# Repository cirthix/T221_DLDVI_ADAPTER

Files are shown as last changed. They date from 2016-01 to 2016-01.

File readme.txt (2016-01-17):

This is the T221 DLDVI Adapter.  It allows DLDVI video signals to drive the DG5/DGM/DGP variants of the IBM T221 and is functionally similar to the IBM 'converter box'.
	
The 'Outputs' directory contains all information needed to create or debug one.

There have been minimal (mostly cosmetic) changes from the actual production run due some file conversion and cleanup.

See 'LICENSE.TXT' for license information.

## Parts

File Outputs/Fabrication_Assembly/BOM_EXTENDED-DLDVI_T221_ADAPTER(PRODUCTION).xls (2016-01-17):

Quantity | Designator | Footprint | Library Reference | Tolerance(%) | Value | Voltage Rating | Manufacturer | Part | Notes | Power Dissipation(mW) | Supplier | Supplier Part #
3.0 | C44, C45, C46 | SMD_0402_CAP | Cap Semi | 10% | 100nF | 10V | Generic | Capacitor | Specified voltage is minimum. May substitute for higher-voltage part. May substitute with tighter tolerance part. |  | Digikey | GRM155R62A104ME14D
2.0 | DVI1, DVI2 | DVI-I CONNECTOR | DVI-I CONNECTOR |  |  |  | TE Connectivity | 1-1734148-1 | Verify footprint before substituting |  | Digikey | 1-1734148-1-ND
2.0 | J2, J3 | LFH-60 | LFH-60 CONNECTOR |  |  |  | Molex | 0015922250 |  |  | Digikey | WM5015-ND
3.0 | Q1, Q3, Q4 | SOT323 | NMOS |  |  | 60Vds 20Vgs | Fairchild | BSS138k | If substituting, verify threshold voltage compatibility |  | Digikey | BSS138KCT-ND
1.0 | Q2 | SOT323 | PMOS |  |  | 50Vds 20Vgs | Fairchild | BSS84 | If substituting, verify threshold voltage compatibility |  | Digikey | BSS84CT-ND
12.0 | R6, R7, R8, R9, R10, R11, R12, R13, R14, R15, R16, R17 | SMD_0402_RES | RES1 | 5% | 16.7R |  | Generic | Resistor | May substitute with tighter tolerance part. | 63 | Digikey | P16.5LCT-ND
2.0 | R18, R19 | SMD_0402_RES | RES1 | 5% | 1KR |  | Generic | Resistor | May substitute with tighter tolerance part. | 63 | Digikey | P1.00KLCT-ND
9.0 | R20, R21, R22, R23, R25, R26, R27, R28, R29 | SMD_0402_RES | Res3 | 5% | 10K |  | Generic | Resistor | May substitute with tighter tolerance part. | 63 | Digikey | P10.0KLCT-ND
3.0 | U5, U6, U7 | SOIC8 + MSOP8 inline | 24C02 |  |  | 5V | ST Microelectronics | M24C02-FMN6TP | Other 5V 1K eeproms will work. |  | Digikey | 497-15748-1-ND

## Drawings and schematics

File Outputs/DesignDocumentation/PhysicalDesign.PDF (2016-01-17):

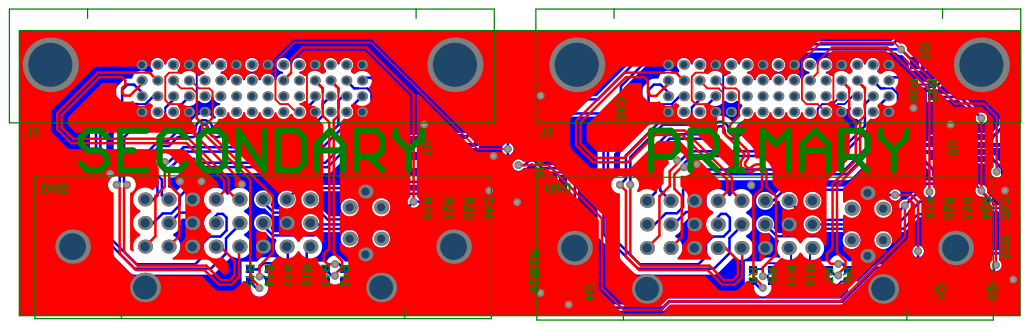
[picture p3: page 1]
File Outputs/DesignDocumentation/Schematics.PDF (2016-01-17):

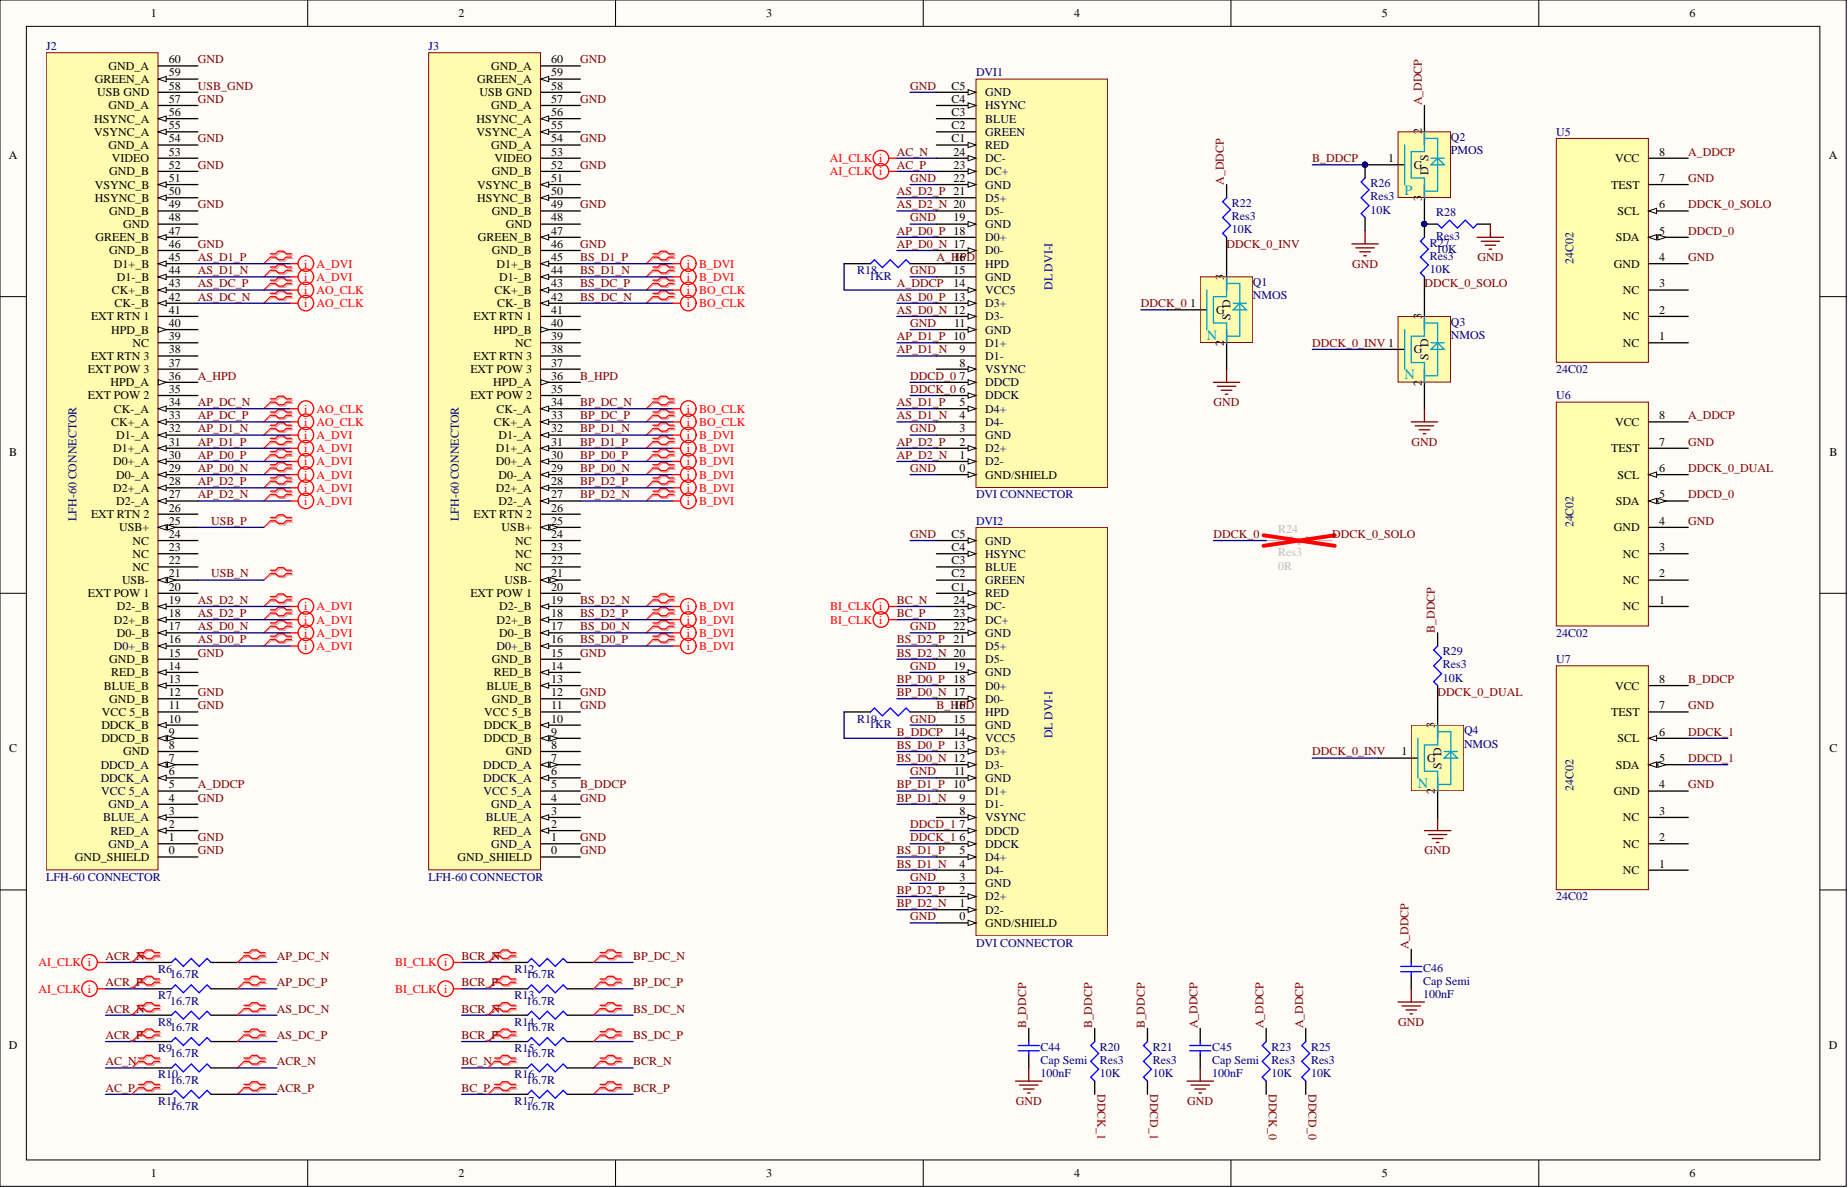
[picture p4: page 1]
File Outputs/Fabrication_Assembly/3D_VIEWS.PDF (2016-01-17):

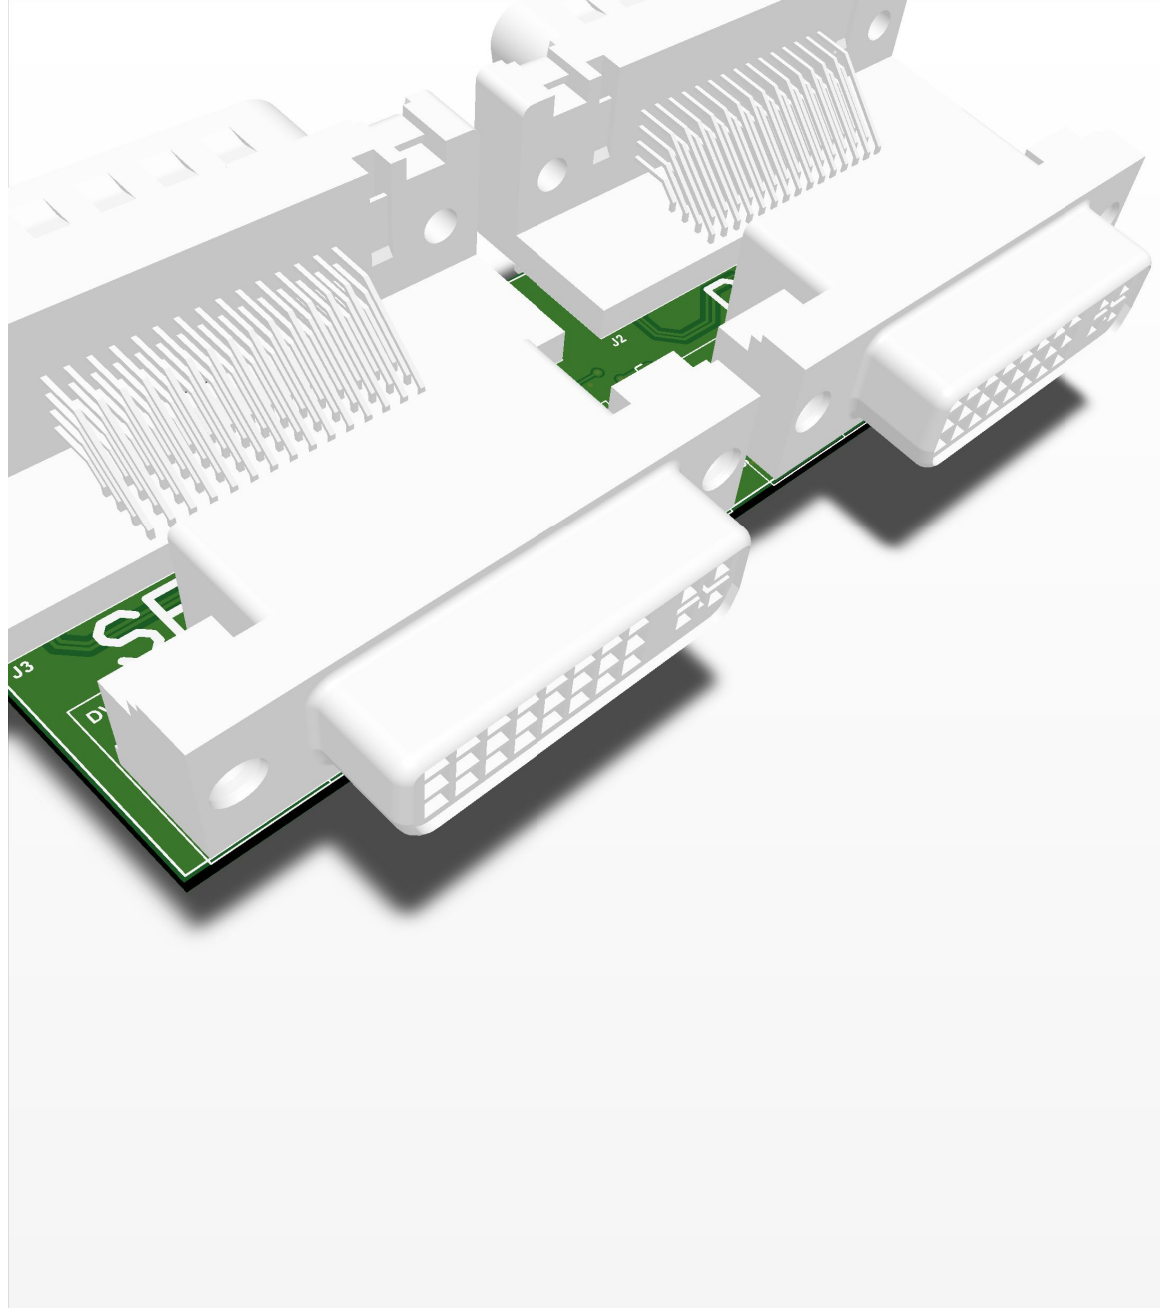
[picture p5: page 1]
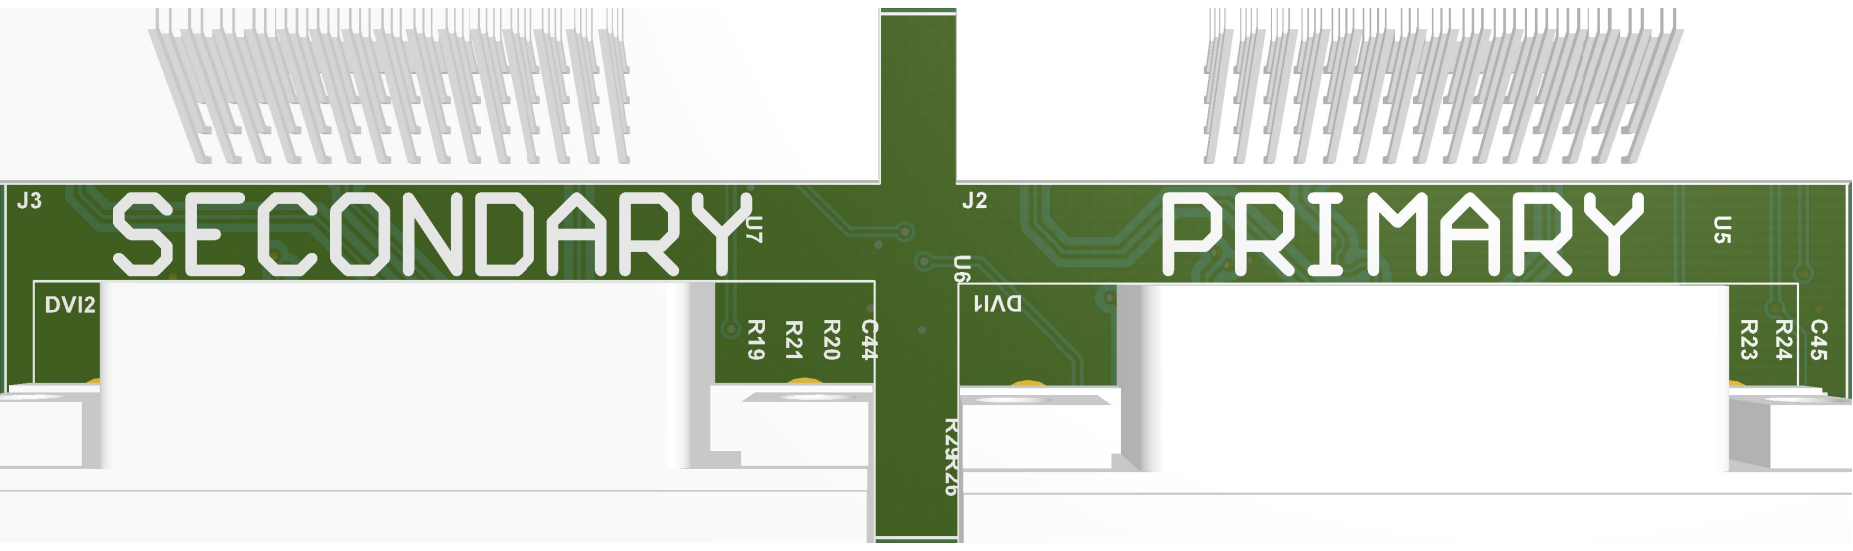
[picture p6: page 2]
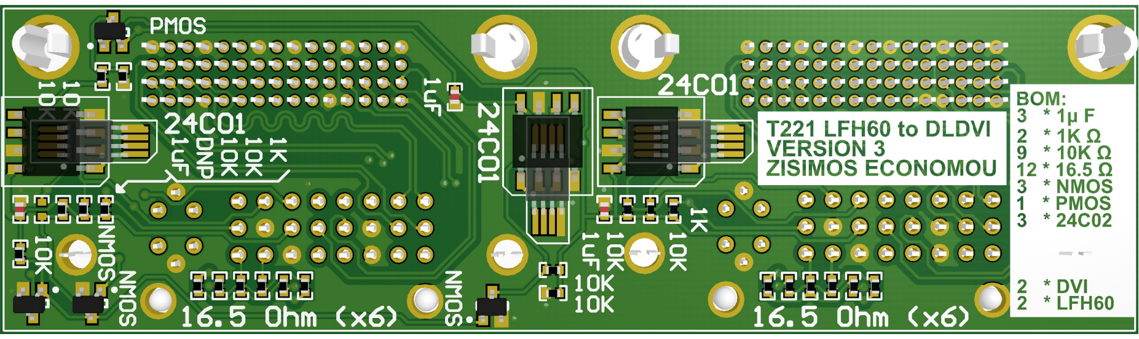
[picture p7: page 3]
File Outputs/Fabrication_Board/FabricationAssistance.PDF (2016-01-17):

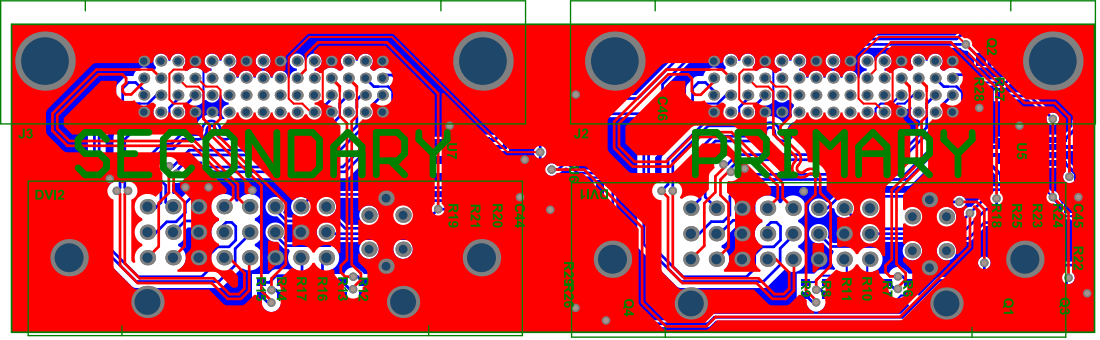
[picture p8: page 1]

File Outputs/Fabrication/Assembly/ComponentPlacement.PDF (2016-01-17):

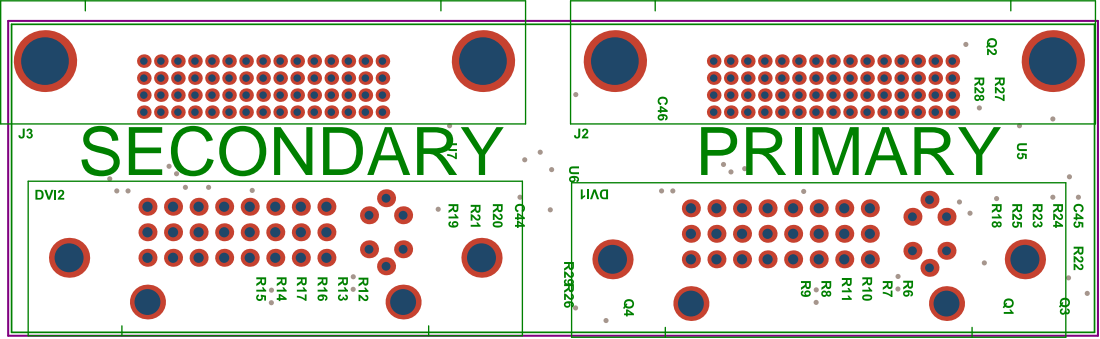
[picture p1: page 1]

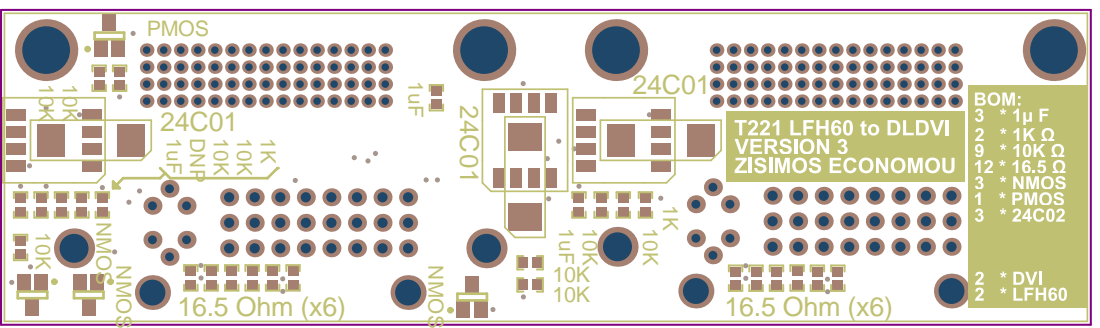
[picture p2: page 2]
16.5 Ohm (x6)
